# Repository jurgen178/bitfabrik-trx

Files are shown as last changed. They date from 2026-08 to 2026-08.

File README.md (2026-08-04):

# Modular HF SSB Transceiver (Superhet, 9 MHz IF, ESP32 Web Interface)

⚠️ **Work in Progress (WIP) - Active Development**

This repository contains a modular shortwave (HF) amateur radio transceiver currently under development. The project balances a classic, stable analog hardware design with modern network control. 

* **Current State:** Pre-alpha / Experimental. The prototype is initially built for the **40m band**, but engineered from scratch to scale across all HF bands from 160m to 10m.
* **Documentation:** Detailed wiring, schematics, and setup instructions will be published once the hardware architecture and software interfaces stabilize.

---

## 🔍 Key Technical Features (In Progress)

* **Architecture:** Classic Superhet design featuring a 9 MHz Intermediate Frequency (IF) with discrete IF amplification and built-in AGC.
* **Mixing System:** Fully bidirectional passive ADE-1 ring mixer utilized for both Receive (RX) and Transmit (TX) switching via relays.
* **Signal Chain:** 
  * **RX:** SA612 product detector paired with an TDA7052A audio amplifier.
  * **TX:** TL072 microphone preamp, SA612 SSB modulator, and a single-ended RD16HHF1 PA stage aiming for 15W output with custom L-matching.
* **Control & Oscillators:** Dual AD9850 DDS modules (independent LO and BFO generation) orchestrated by an ESP32.
* **Web UI Control:** Integrated standalone Wi-Fi network interface hosted on the ESP32. Enables platform-independent remote tuning, band switching, mode selection (USB/LSB/CW/RTTY), and a built-in Morse/RTTY interface which will be expanded to support common digital transfer modes.

---

## 📁 Repository Structure

* `/src` — Contains the early-stage ESP32 control software, DDS configuration routines, and the wireless web server interface code.
* *(Upcoming)* `/hardware` — Schematics, component lists, and layout guides tailored for the Manhattan-style build approach will be uploaded here later.

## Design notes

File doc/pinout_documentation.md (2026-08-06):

# Anschlussplan (Pinout) - Arduino Nano ESP32

Diese Dokumentation zeigt die exakte physische Verbindung für das **Hosyond 4.0" TN Display** (ST7796S & FT5x06) und alle weiteren Hardware-Komponenten.

## 1. Gemeinsamer I2C-Bus (OLEDs, MCP23017 & Touch)
Alle I2C-Geräte hängen parallel an denselben zwei Leitungen.
- **CTP_SDA** (Touch) geht an **A4**
- **CTP_SCL** (Touch) geht an **A5**

| Signal | GPIO (Code) | Board-Label |
| :--- | :--- | :--- |
| **SDA** | 11 | **A4** |
| **SCL** | 12 | **A5** |

## 2. SPI-Bus (TFT-Display)
| Signal | GPIO (Code) | Board-Label | Display-Pin |
| :--- | :--- | :--- | :--- |
| **SCK** | 48 | **D13** | 7 (SCK) |
| **MOSI** | 38 | **D11** | 6 (SDI) |
| **MISO** | 47 | **D12** | 9 (SDO) |
| **LCD_CS** | 18 | **D9** | 3 (CS) |
| **LCD_RS** | 21 | **D10** | 5 (RS/DC) |
| **TFT_RST** | -1 | **RST** | 4 (LCD_RST) & 11 (CTP_RST) |

## 3. DDS BUS (Shared Architektur)
| Signal | GPIO (Code) | Board-Label | Ziel |
| :--- | :--- | :--- | :--- |
| **DDS_DATA** | 8 | **D5** | DATA (beide Module) |
| **DDS_WCLK** | 9 | **D6** | WCLK (beide Module) |
| **DDS_RESET**| 17 | **D8** | RESET (beide Module) |
| **LO_FQUD**  | 10 | **D7** | FQUD (nur VFO) |
| **BFO_FQUD** | 44 | **D0** | FQUD (nur BFO) |

## 4. Audio & Bedienelemente
| Funktion | GPIO (Code) | Board-Label |
| :--- | :--- | :--- |
| **Audio Volume PWM** | 13 | **A6** |
| **Encoder A** | 5 | **D2** |
| **Encoder B** | 6 | **D3** |
| **Encoder Btn** | 7 | **D4** |
| **PTT Taste** | 4 | **A3** |
| **SWR FWD** | 2 | **A1** |
| **SWR REF** | 3 | **A2** |
| **RSSI / S-Meter**| 1 | **A0** |
| **ZF_AGC_PWM** | 14 | **A7** |
| **Mic Gain CS**| 43 | **D1** |

## 5. MCP23017 Ausgänge (Getrennte RX/TX Filterbänke)
Der Transceiver nutzt zwei unabhängige Gruppen von je 6 Relais für Empfangs- (RX) und Sende-Filter (TX). Ein automatisches Interlock in der Software stellt sicher, dass immer nur die benötigte Gruppe aktiv ist.

| MCP-Pin | Gruppe | Funktion |
| :--- | :--- | :--- |
| **0 - 5** | **RX Filter** | Slots für 10m, 15m, 20m, 40m, 80m, 160m (Empfang) |
| **8 - 13**| **TX Filter** | Slots für 10m, 15m, 20m, 40m, 80m, 160m (Senden) |
| **7** | **TX Control** | **PA_ACTIVE** / Haupt-Antennenrelais |
| **6** | **RESERVE** | Frei |
| **14 - 15**| **RESERVE** | Frei |

## 6. Ressourcen-Check
- **Native GPIOs**: 0 frei (Alle Header-Pins belegt).
- **MCP23017 Pins**: 8 frei.
- **Interne RGB-LED**: Rot (46), Grün (0), Blau (45) - für Statusmeldungen reserviert.

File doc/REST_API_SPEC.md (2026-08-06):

# BITFABRIK Transceiver REST API Specification

This document describes the REST API and communication interfaces for the BITFABRIK Transceiver.

## 1. Web Interfaces

| Method | Path | Description |
| :--- | :--- | :--- |
| `GET` | `/` | Main Control Dashboard (HTML) |
| `GET` | `/bands` | Band Configuration Editor (HTML) |

## 2. Configuration API

| Method | Path | Description |
| :--- | :--- | :--- |
| `GET` | `/bands.json` | Retrieves current band configuration in JSON format. |
| `POST` | `/bands.json` | Saves a new band configuration. Triggers ESP restart. |
| `DELETE` | `/bands.json` | Resets band configuration to defaults. Triggers ESP restart. |

### Band Configuration Schema
Die Datei `/bands.json` steuert die Hardware-Filter und Frequenzbereiche.
**Struktur (Array von Objekten):**
```json
[
  {
    "id": "40m",
    "min": 7000000,
    "max": 7200000,
    "def": 7047000,
    "rx_filter": 3,
    "tx_filter": 3,
    "usb": false,
    "active": true
  }
]
```

### Band Management Examples
**Band-Tabelle hochladen (Überschreiben):**
```bash
curl -X POST -H "Content-Type: application/json" --data-binary @my_bands.json "http://192.168.1.110/bands.json"
```

**Band-Tabelle zurücksetzen (löscht /bands.json auf dem ESP):**
```bash
curl -X DELETE "http://192.168.1.110/bands.json"
```

## 3. Real-Time Status & Control

### Status Update
**`GET /api/v1/status`**
Returns the complete system state as a JSON object.

### Device Control
**`GET/POST /api/v1/control`**
Updates hardware parameters. Multiple parameters can be combined in one request.

**Parameters:**
*   `ui_mode`: `RADIO`, `GEN`, `SETTINGS`, `RIT`
*   `freq`: Frequency in Hz (e.g., `7100000`)
*   `vol`: Audio Volume (0-100)
*   `pwr`: PA Drive Power (0-100)
*   `mic`: Mic Gain (0-100)
*   `band`: Band Index (0-5)
*   `mode`: Digital Mode (0=Morse, 1=RTTY)
*   `vfo_set`: Switch VFO (0=A, 1=B)
*   `vfo_copy`: Trigger A=B sync (any value)
*   `rit_enable`: Enable RIT (0=Off, 1=On)
*   `rit_offset`: RIT Offset in Hz
*   `mem_store`: Store current VFO in Memory Slot (0-9)
*   `mem_recall`: Recall VFO from Memory Slot (0-9)
*   `step`: Tuning Step Index
*   `vox_enable`: Toggle/Set VOX state
*   `vox_thresh`: VOX ADC Threshold (0-4095)
*   `vox_delay`: VOX Release Delay in ms

## 4. Messaging & Transmission

### Digital Transmission
**`GET/POST /api/v1/transmit`**
Queues text for digital transmission.
*   `text`: The string to transmit.

### Radio Email (APRS/JS8 Gateway)
**`GET/POST /api/v1/email`**
Sends an email via radio gateway.
*   `to`: Recipient email address.
*   `msg`: Email body (max 67-100 chars).
*   `gw`: Gateway type (`aprs` or `js8`).

## 5. Streaming & Real-Time Events

### WebSocket
**`WS /ws`**
Primary bi-directional channel for real-time operation.
*   **Downlink:** Sends `JSON_STATUS:{...}` and `RX:<char>`
*   **Uplink:** Accepts `SET:<key>:<value>`, `TX:<text>`, and `MAIL|<to>|<msg>|<gw>`

### Server-Sent Events (SSE)
**`GET /api/v1/rx/stream`**
Event stream for decoded RX characters.
*   Event: `rx_char`

## 6. Usage Examples

Replace `192.168.1.110` with your transceiver's actual IP address.

### Control Examples (curl)
**Set frequency to 7.100 MHz:**
```bash
curl "http://192.168.1.110/api/v1/control?freq=7100000"
```

### PowerShell Example (Windows)
PowerShell ist ideal für kleine Desktop-Scripts.
**Frequenz setzen und Status abrufen:**
```powershell
# Frequenz auf 14.250 MHz setzen
Invoke-RestMethod -Uri "http://192.168.1.110/api/v1/control?freq=14250000"

# Aktuellen Status abholen und Frequenz anzeigen
$status = Invoke-RestMethod -Uri "http://192.168.1.110/api/v1/status"
Write-Host "Aktuelle Frequenz: $($status.freq / 1e6) MHz"
```

### Python Example
Ideal für Automatisierung oder Logging. Benötigt die `requests` Bibliothek.
```python
import requests

# Frequenz setzen
params = {'freq': 7047000, 'vol': 40}
r = requests.get("http://192.168.1.110/api/v1/control", params=params)

# Status auslesen
status = requests.get("http://192.168.1.110/api/v1/status").json()
print(f"SWR: {status['swr']} | Power: {status['power_w']}W")
```

### JavaScript / Node.js (Fetch API)
```javascript
// Frequenz ändern
fetch("http://192.168.1.110/api/v1/control?freq=3600000")
  .then(response => console.log("Status: " + response.status));

// Status periodisch abfragen
async function getStatus() {
  const res = await fetch("http://192.168.1.110/api/v1/status");
  const data = await res.json();
  console.log(`RSSI: ${data.rssi} dBm`);
}
```

### Messaging Examples

**Set Volume to 50% and switch to VFO B:**
```bash
curl "http://192.168.1.110/api/v1/control?vol=50&vfo_set=1"
```

**Toggle VOX System:**
```bash
curl "http://192.168.1.110/api/v1/control?vox_enable=1"
```

### Messaging Examples
**Send "CQ CQ DE BITFABRIK" in current digital mode:**
```bash
curl --data "text=CQ CQ DE BITFABRIK" "http://192.168.1.110/api/v1/transmit"
```

**Send a Radio Email via APRS Gateway:**
```bash
curl "http://192.168.1.110/api/v1/email?to=test@example.com&msg=Hello+from+Radio&gw=aprs"
```

### WebSocket Example (JavaScript)
```javascript
const ws = new WebSocket('ws://192.168.1.110/ws');

ws.onmessage = (event) => {
    if (event.data.startsWith('JSON_STATUS:')) {
        const status = JSON.parse(event.data.substring(12));
        console.log("Current Frequency:", status.freq);
    }
};

// Send command via WebSocket
ws.onopen = () => {
    ws.send("SET:freq:14250000");
};
```

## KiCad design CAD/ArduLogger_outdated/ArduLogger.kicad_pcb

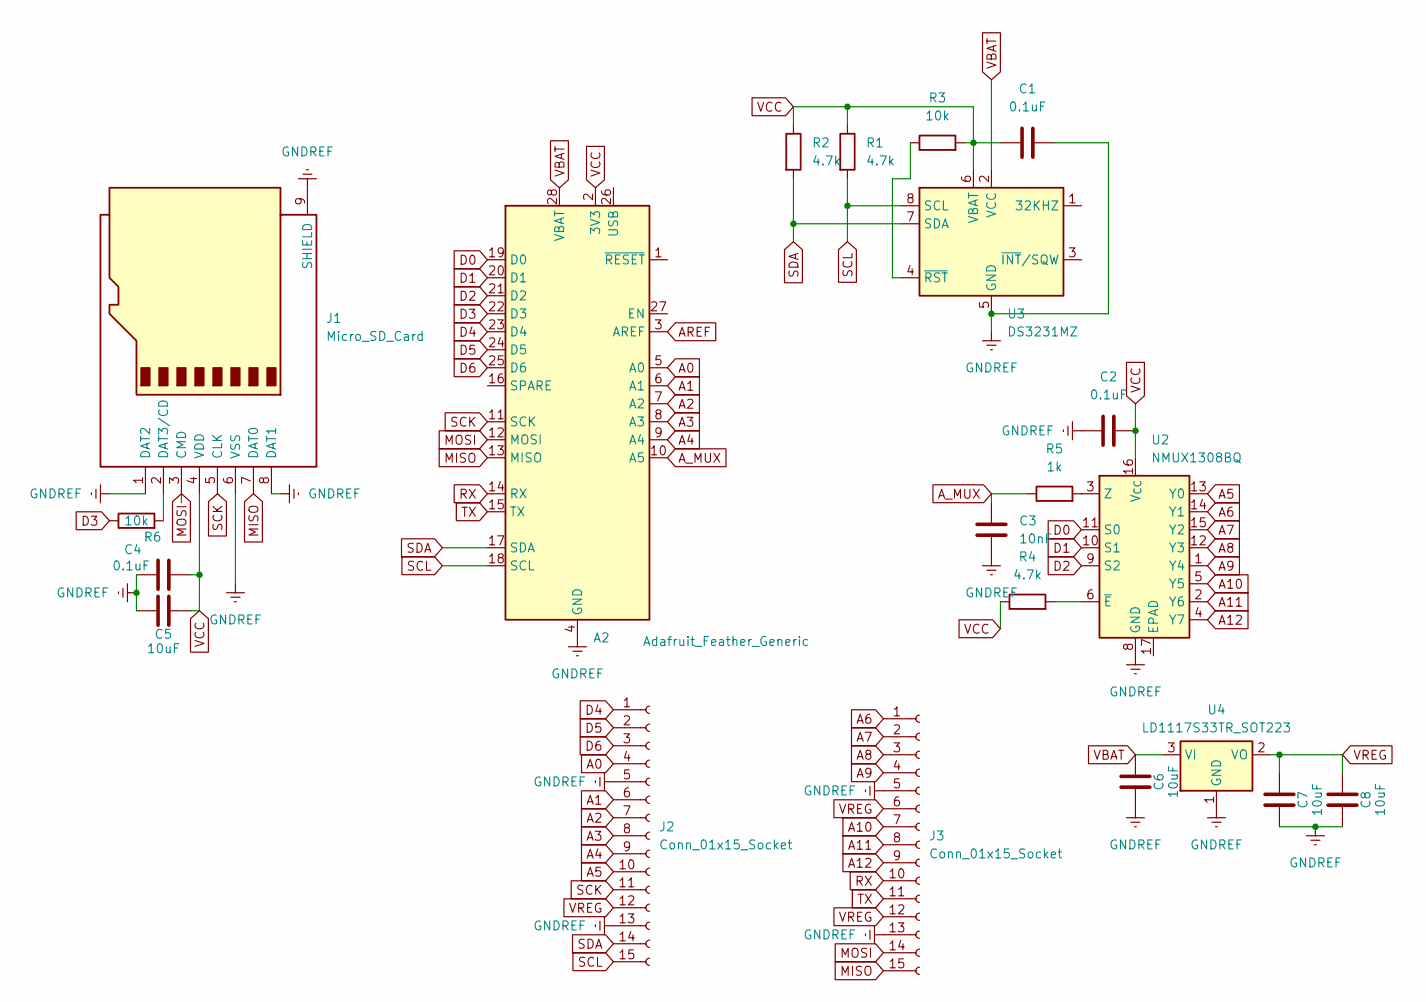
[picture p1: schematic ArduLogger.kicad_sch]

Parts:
A2: Adafruit_Feather_Generic; Adafruit_Feather
C1, C2, C4: 0.1uF; C_0603_1608Metric
C3: 10nF; C_0603_1608Metric
C5, C6, C7, C8: 10uF; C_0603_1608Metric
J1: Micro_SD_Card; microSD_HC_Wuerth_693072010801
J2, J3: Conn_01x15_Socket; PhoenixContact_MSTBVA_2,5_15-G-5,08_1x15_P5.08mm_Vertical
R1, R2, R4: 4.7k; R_0603_1608Metric
R3, R6: 10k; R_0603_1608Metric
R5: 1k; R_0603_1608Metric
U2: NMUX1308BQ; DHVQFN-16-1EP_2.5x3.5mm_P0.5mm_EP1x2mm
U3: DS3231MZ; SOIC-8_3.9x4.9mm_P1.27mm
U4: LD1117S33TR_SOT223; SOT-223-3_TabPin2

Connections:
A0: A2.5 (A0), J2.4
A1: A2.6 (A1), J2.6
A2: A2.7 (A2), J2.7
A3: A2.8 (A3), J2.8
A4: A2.9 (A4), J2.9
A5: J2.10, U2.13 (Y0)
A6: J3.1, U2.14 (Y1)
A7: J3.2, U2.15 (Y2)
A8: J3.3, U2.12 (Y3)
A9: J3.4, U2.1 (Y4)
A10: J3.7, U2.5 (Y5)
A11: J3.8, U2.2 (Y6)
A12: J3.9, U2.4 (Y7)
AREF: A2.3 (AREF)
A_MUX: A2.10 (A5), C3.1, R5.1
D0: A2.19 (D0), U2.11 (S0)
D1: A2.20 (D1), U2.10 (S1)
D2: A2.21 (D2), U2.9 (S2)
D3: A2.22 (D3), R6.1
D4: A2.23 (D4), J2.1
D5: A2.24 (D5), J2.2
D6: A2.25 (D6), J2.3
GNDREF: A2.4 (GND), C1.2, C2.1, C3.2, C4.1, C5.1, C6.1, C7.1, C8.1, J1.1 (DAT2), J1.6 (VSS), J1.8 (DAT1), J1.9 (SHIELD), J2.5, J2.13, J3.5, J3.13, U2.8 (GND), U3.5 (GND), U4.1 (GND)
MISO: A2.13 (MISO), J1.7 (DAT0), J3.15
MOSI: A2.12 (MOSI), J1.3 (CMD), J3.14
unnamed: J1.2 (DAT3/CD), R6.2
unnamed: R5.2, U2.3 (Z)
unnamed: R4.2, U2.6 (~E)
unnamed: R3.1, U3.4 (~RST)
RX: A2.14 (RX), J3.10
SCK: A2.11 (SCK), J1.5 (CLK), J2.11
SCL: A2.18 (SCL), J2.15, R1.2, U3.8 (SCL)
SDA: A2.17 (SDA), J2.14, R2.2, U3.7 (SDA)
TX: A2.15 (TX), J3.11
VBAT: A2.28 (VBAT), C6.2, U3.2 (VCC), U4.3 (VI)
VCC: A2.2 (3V3), C1.1, C2.2, C4.2, C5.2, J1.4 (VDD), R1.1, R2.1, R3.2, R4.1, U2.16 (V_{CC}), U3.6 (VBAT)
VREG: C7.2, C8.2, J2.12, J3.6, J3.12, U4.2 (VO)

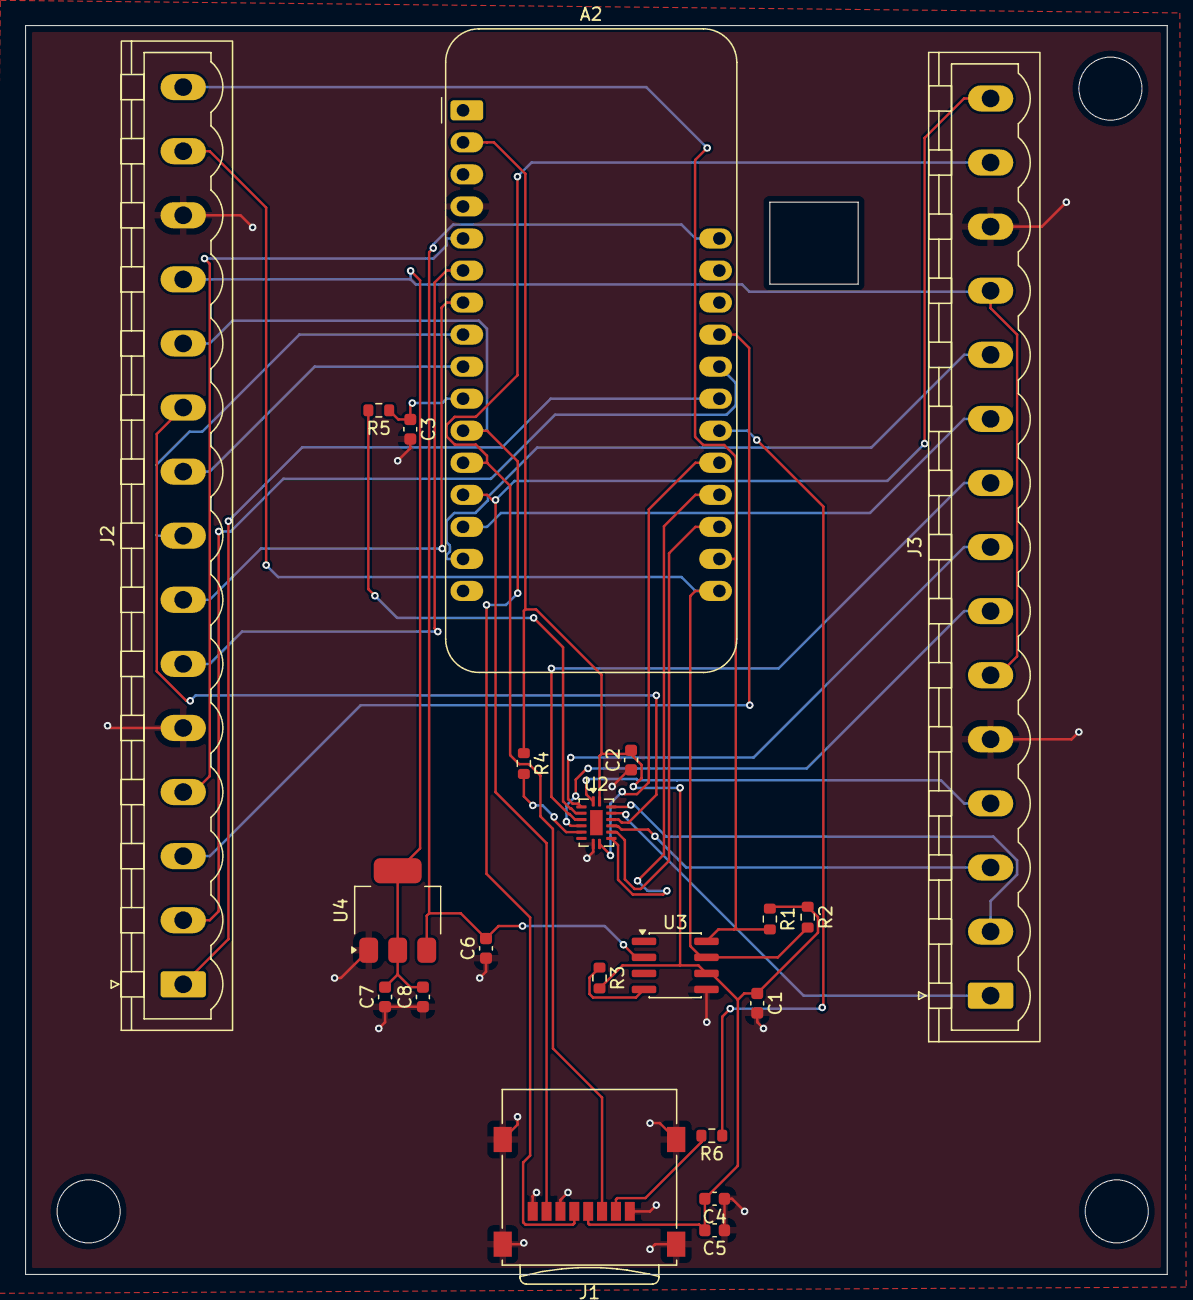
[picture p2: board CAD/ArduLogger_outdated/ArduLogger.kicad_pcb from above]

Board: 2 copper layers, 90.5 x 99.0 mm, 21 parts (0 on the bottom side), 36 nets.

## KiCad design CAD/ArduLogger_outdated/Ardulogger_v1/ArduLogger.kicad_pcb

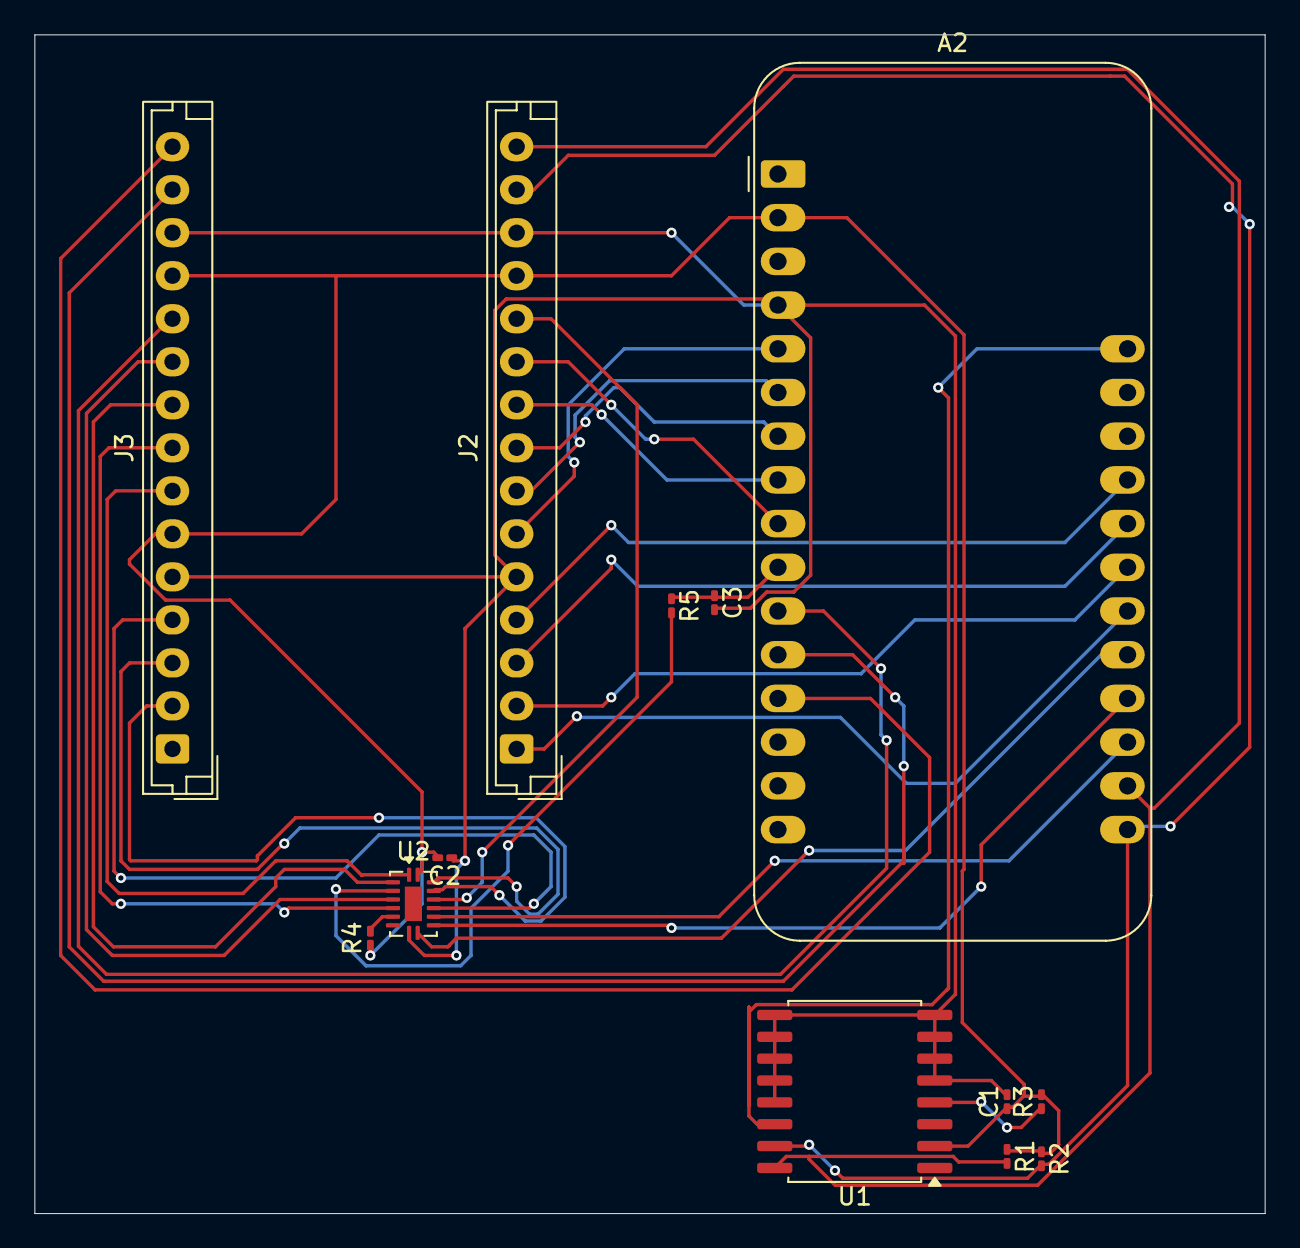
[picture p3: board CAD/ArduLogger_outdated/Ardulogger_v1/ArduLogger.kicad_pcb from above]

Board: 2 copper layers, 71.5 x 68.5 mm, 13 parts (0 on the bottom side), 32 nets.

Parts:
A2: Adafruit_Feather_Generic; Adafruit_Feather
C1, C2: 0.1uF; C_0201_0603Metric_Pad0.64x0.40mm_HandSolder
C3: 10nF; C_0201_0603Metric_Pad0.64x0.40mm_HandSolder
J2, J3: Conn_01x15_Socket; JST_EH_B15B-EH-A_1x15_P2.50mm_Vertical
R1, R2, R4: 4.7k; R_0201_0603Metric_Pad0.64x0.40mm_HandSolder
R3: 10k; R_0201_0603Metric_Pad0.64x0.40mm_HandSolder
R5: 100; R_0201_0603Metric_Pad0.64x0.40mm_HandSolder
U1: DS3231M; SOIC-16W_7.5x10.3mm_P1.27mm
U2: NMUX1308BQ; DHVQFN-16-1EP_2.5x3.5mm_P0.5mm_EP1x2mm

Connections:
A0: A2.5 (A0), J2.6
A1: A2.6 (A1), J2.7
A2: A2.7 (A2), J2.8
A3: A2.8 (A3), J2.9
A4: A2.9 (A4), J2.10
A5: J2.11, U2.13 (Y0)
A6: J3.2, U2.14 (Y1)
A7: J3.3, U2.15 (Y2)
A8: J3.4, U2.12 (Y3)
A9: J3.7, U2.1 (Y4)
A10: J3.8, U2.5 (Y5)
A11: J3.9, U2.2 (Y6)
A12: J3.10, U2.4 (Y7)
A_MUX: A2.10 (A5), C3.1, R5.1
D0: A2.19 (D0), U2.11 (S0)
D1: A2.20 (D1), U2.10 (S1)
D2: A2.21 (D2), U2.9 (S2)
D3: A2.22 (D3), J2.1
D4: A2.23 (D4), J2.2
D5: A2.24 (D5), J2.3
D6: A2.25 (D6), J2.4
GNDREF: A2.4 (GND), C1.2, C2.1, C3.2, J2.5, J2.13, J3.5, J3.13, U1.5 (GND), U1.6 (GND), U1.7 (GND), U1.8 (GND), U1.9 (GND), U1.10 (GND), U1.11 (GND), U1.12 (GND), U1.13 (GND), U2.8 (GND)
MISO: A2.13 (MISO), J3.15
MOSI: A2.12 (MOSI), J3.14
unnamed: A2.28 (VBAT), U1.14 (VBAT)
unnamed: R3.1, U1.4 (~RST)
unnamed: R5.2, U2.3 (Z)
unnamed: R4.2, U2.6 (~E)
SCK: A2.11 (SCK), J3.11
SCL: A2.18 (SCL), J2.15, R1.2, U1.16 (SCL)
SDA: A2.17 (SDA), J2.14, R2.2, U1.15 (SDA)
VCC: A2.2 (3V3), C1.1, C2.2, J2.12, J3.6, J3.12, R1.1, R2.1, R3.2, R4.1, U1.2 (VCC), U2.16 (V_{CC})

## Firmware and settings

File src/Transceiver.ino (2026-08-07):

/**
 * ── BITFABRIK Transceiver v1.0 ──────────────────────────────────────────
 */

#include <FFat.h>
#include "Constants.h"
#include "Globals.h"
#include "Hardware.h"
#include "Display.h"
#include "DigitalEngine.h"
#include "Network.h"
#include "EncoderActions.h"
#include "RadioEngine.h"
#include "AudioManager.h"
#include "SettingsManager.h"
#include "LogManager.h"

// ── GLOBAL STATE ALLOCATION ───────────────────────────────────────────────

std::atomic<bool> g_tx(false);
std::atomic<bool> g_mcpOk(false);
std::atomic<unsigned long> g_lastActivityTime(0);
SyncState g_sync;

// UI Synchronization
std::atomic<bool> g_guiNeedsUpdate(true);
TaskHandle_t  g_networkTaskHandle = NULL;

// System Health
volatile int g_cpuLoad0 = 0;
volatile int g_cpuLoad1 = 0;
volatile int g_wifiRssi = -100;
volatile int g_webClients = 0;
volatile int g_netActivity = 0;

// Encoder State Machine
volatile int  g_encPos      = 0;
volatile unsigned long g_lastEncMove = 0;
volatile unsigned long g_encInterval = 999;
volatile uint8_t g_oldEncState = 0;
volatile int8_t  s_encAccum  = 0;
const int8_t ENC_STATES[] = { 0, -1, 1, 0, 1, 0, 0, -1, -1, 0, 0, 1, 0, 1, -1, 0 };

// ── HARDWARE SINGLETONS ───────────────────────────────────────────────────

LGFX_TRX tft;
Adafruit_SSD1306 display1(SCREEN_WIDTH, SCREEN_HEIGHT, &Wire, OLED_RESET);
Adafruit_SSD1306 display2(SCREEN_WIDTH, SCREEN_HEIGHT, &Wire, OLED_RESET);
Adafruit_MCP23X17 mcp;
Preferences preferences;
EncoderManager encManager;

SemaphoreHandle_t g_mutex;
SemaphoreHandle_t g_hwMutex;

// ── CONSTANT DATA (defined in Constants.cpp) ─────────────────────────────
// extern declarations are in Globals.h

// ── SYSTEM BOOT ───────────────────────────────────────────────────────────

void setup()
{
  Serial.begin(115200);
  delay(2000); // Give user time to open monitor
  Serial.println("\n\n--- BITFABRIK Transceiver Start ---");

  // Init concurrency locks
  g_mutex = xSemaphoreCreateMutex();
  g_hwMutex = xSemaphoreCreateRecursiveMutex();

  // Basic I/O
  pinMode(LED_RED, OUTPUT);
  digitalWrite(LED_RED, HIGH);

  // FFat Filesystem
  Serial.println("FS: Initializing FFat...");
  if (!FFat.begin(false)) {
      Serial.println("FS: FFat mount failed. Formatting...");
      FFat.begin(true);
  }
  Serial.println("FS: OK");

  Serial.println("I2C: Initializing...");
  Wire.begin();
  Wire.setClock(200000); // Stable 200kHz for multiple devices
  Wire.setTimeOut(100); // Prevent hang if device missing
  Serial.println("I2C: Scan start...");
  for (uint8_t address = 1; address < 127; address++)
  {
    Wire.beginTransmission(address);
    if (Wire.endTransmission() == 0)
    {
      Serial.printf("I2C: Found device at 0x%02X\n", address);
    }
  }

  // MCP23017 Expander Init
  Serial.println("MCP: Initializing...");
  if (!mcp.begin_I2C(0x27))
  {
      Serial.println("MCP: ERR - Not found at 0x27");
      g_mcpOk = false;
  }
  else
  {
      Serial.println("MCP: OK");
      g_mcpOk = true;
      // Initialize all 16 pins to a safe state
      for (int i = 0; i < 16; i++)
      {
          if (i == MCP_PIN_PTT)
          {
              mcp.pinMode(i, INPUT_PULLUP);
          }
          else
          {
              mcp.pinMode(i, OUTPUT);
              mcp.digitalWrite(i, LOW); // Ensure all relays/PA_ACTIVE are OFF
          }
      }
  }

  // Hardware Pin Config
  Serial.println("HW: Configuring pins...");
  const int busPins[] = { DDS_DATA, DDS_WCLK, DDS_RESET, LO_FQUD, BFO_FQUD };
  for (int p : busPins)
  {
      pinMode(p, OUTPUT);
  }
  pinMode(AUDIO_VOLUME_PWM, OUTPUT);
  pinMode(ZF_AGC_PWM, OUTPUT);
  pinMode(MIC_CS, OUTPUT);
  digitalWrite(MIC_CS, HIGH);
  pinMode(ENC_A, INPUT);
  pinMode(ENC_B, INPUT);
  pinMode(ENC_BTN, INPUT_PULLUP);

  // Encoder ISR Setup
  g_oldEncState = (digitalRead(ENC_A) << 1) | digitalRead(ENC_B);
  if (ENC_TYPE == 1)
  {
    attachInterrupt(digitalPinToInterrupt(ENC_A), encISR_Optical, CHANGE);
    attachInterrupt(digitalPinToInterrupt(ENC_B), encISR_Optical, CHANGE);
  }
  else
  {
    attachInterrupt(digitalPinToInterrupt(ENC_A), encISR, CHANGE);
    attachInterrupt(digitalPinToInterrupt(ENC_B), encISR, CHANGE);
  }

  // Visuals & Touch
  Serial.println("TFT: Initializing (ST7796S)...");
  tft.init();
  tft.setRotation(1);
  tft.fillScreen(TFT_BLACK);
  Serial.println("TFT: OK");

  Serial.println("OLED: Initializing Display 1 (0x3C)...");
  if(!display1.begin(SSD1306_SWITCHCAPVCC, OLED_ADRESSE_A))
  {
    Serial.println("OLED 1: ERR");
  }
  else
  {
    display1.clearDisplay();
    display1.display(); // Force clear to avoid "snow" at start
    Serial.println("OLED 1: OK");
  }

  Serial.println("OLED: Initializing Display 2 (0x3D)...");
  if(!display2.begin(SSD1306_SWITCHCAPVCC, OLED_ADRESSE_B))
  {
    Serial.println("OLED 2: ERR");
  }
  else
  {
    display2.clearDisplay();
    display2.display();
    Serial.println("OLED 2: OK");
  }

  Serial.println("DDS: Syncing bus...");
  dds_reset(); // Bus synchronization

  Serial.println("Settings: Loading...");
  settings.begin();
  logger.begin();

  Serial.println("Audio: Starting PWM...");
  audio.begin();

  Serial.println("Radio: Loading dynamic configuration...");
  radio.loadBandsFromJson();

  Serial.println("Radio: Setting default band...");
  ui.begin();
  radio.selectBand(radio.getBand());
  ui.drawFullUI();

  encManager.begin();

  // Multi-Core Task Scheduling - START LAST
  Serial.println("OS: Starting Background Services...");
  xTaskCreatePinnedToCore(TaskNetwork, "Network", 8192, NULL, 1, NULL, 0); // Core 0: Comm Background
  xTaskCreatePinnedToCore(TaskDigital, "Digital", 4096, NULL, 2, NULL, 0); // Core 0: FSK Timing

  Serial.println("OS: Starting Radio...");
  xTaskCreatePinnedToCore(TaskRadio,   "Radio",   8192, NULL, 3, NULL, 1); // Core 1: Hardware High Priority

  Serial.println("BOOT COMPLETE.");
}

void loop()
{
  // Tasks are managed by FreeRTOS. loop() just yields.
  vTaskDelay(pdMS_TO_TICKS(1000));
}

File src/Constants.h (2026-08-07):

#ifndef CONSTANTS_H
#define CONSTANTS_H

#include <Arduino.h>

/**
 * ── BITFABRIK Transceiver v3.0 ──────────────────────────────────────────
 * Central Hardware Configuration (Pins, Constants, and i18n).
 *
 * Target Board: Arduino Nano ESP32 (ESP32-S3)
 * NOTE: Ensure "By GPIO number (standard)" is selected in Tools -> Pin Numbering.
 * ──────────────────────────────────────────────────────────────────────────
 */

// ── Build Flags ───────────────────────────────────────────────────────────
#define DEBUG_SIM // Enable simulated RSSI/SWR and dummy RX decode (no hardware needed)

// ── Internationalization (i18n) ──────────────────────────────────────────
#define LANG_DE // Standard auf Deutsch für Tests

#if defined(LANG_DE)
  #define L_I2C_OK        "I2C initialisiert (400kHz)"
  #define L_MCP_ERR       "MCP23017 Fehler!"
  #define L_MCP_OK        "MCP23017 initialisiert"
  #define L_ENC_OPTICAL   "Encoder: Optisch (EM14)"
  #define L_ENC_MECHANIC  "Encoder: Mechanisch (KY-040)"
  #define L_TFT_TOUCH_OK  "ILI9488 & Touch bereit"
  #define L_DISP1_ERR     "Display 1 (0x3C) Fehler!"
  #define L_DISP2_ERR     "Display 2 (0x3D) Fehler!"
  #define L_PREFS_SAVED   "Einstellungen gespeichert."
  #define L_SYS_STARTED   "System gestartet."
  #define L_WIFI_CONN     "Verbinde mit Heimnetzwerk..."
  #define L_WIFI_FAIL     "Statische IP Konfiguration fehlgeschlagen!"
  #define L_AP_START      "\n=== Access Point gestartet ==="
  #define L_WIFI_OK       "\n=== WiFi Station verbunden ==="
  #define L_WIFI_ERR      "\n=== Heimnetzwerk nicht erreichbar ==="
  #define L_AP_MSG        "Bitte mit 'TRX-1-Hotspot' verbinden"
  #define L_TX_ON         "Radio Task: TX -> AN"
  #define L_TX_OFF        "Radio Task: TX -> AUS"
  #define L_SWR_ALARM     "!!! SWR ALARM: %.1f !!!"
  #define L_SSE_CONN      "SSE: Client verbunden."
  #define L_API_TX        "API v1: Sende-Anfrage: "
  #define L_SWR_ALARM_AUX "AUX: SWR ALARM!"
  #define L_BAND          "Band"
  #define L_MODE          "Modus"
  #define L_SEQ_RX_TX     "Sequenzer: RX -> TX bereit"
  #define L_SEQ_TX_RX     "Sequenzer: TX -> RX bereit"
  #define L_MEM_CHANNELS  "MEM:"
  #define L_STEP          "Schritt"
  #define L_CALIBRATION   "KALIBRIERUNG"
  #define L_TX_ACTIVE     "TX: AKTIV"
  #define L_RX            "RX"
  #define L_DIGITAL_MODE  "Digital:"
  #define L_TIME_UTC      "Zeit UTC:"
  #define L_TIME          "Zeit:"
  #define L_UPTIME        "Uptime"
  #define L_FREE          "Frei"
  #define L_WAIT_SIGNAL   "Warte auf Signal..."
  #define H_LIVE_MONITOR  "Live Station"
  #define H_SIGNAL_HEALTH "Signal & Status"
  #define H_TUNING_CONTROLS "Abstimmung"
  #define H_DIGI_MSG      "Digitaler Funk"
  #define H_MAIL_GW       "Radio Email Gateway"
  #define H_DECODED       "Decoder Stream"
  #define H_TUNING_KNOB   "Abstimmung"
  #define H_DIGI_MODE     "Digitaler Modus"
  #define H_TRANSMIT      "Senden"
  #define H_CARRIER       "Träger"
  #define H_IDLE          "BEREIT"
  #define H_SENDING       "SENDET"
  #define H_MSG_PLACEHOLDER "Nachricht eingeben..."
  #define H_SEND_BTN      "Senden"
  #define H_DECODED_STREAM "Decodierter Stream"
  #define H_CLEAR_BTN     "Löschen"
  #define H_MEM_CHANNELS  "Speicherkanäle"
  #define H_SAVE_TO       "Speichern in:"
  #define H_STORE_BTN     "Sichern"
  #define H_BAND_MODE     "Band & Modus"
  #define L_MIC_GAIN      "Mic Gain"
  #define L_WAITING       "Warten..."
  #define L_SEND          "Senden"
  #define L_RIT_ON        "RIT AN"
  #define L_RIT_OFF       "RIT AUS"
  #define L_IDLE          "IDLE"
  #define L_SENDING       "SENDET"
  #define L_VOL           "Lautstärke"
  #define TX_PWR_CTRL     "Sendeleistung"
  #define L_MORSE_MODE    "Morse Modus"
  #define L_RTTY_MODE     "RTTY Modus"
  #define L_TX_STATUS     "Sende-Status"
  #define L_MAIL_RECIPIENT "Empfänger"
  #define L_MAIL_BODY     "Inhalt..."
  #define L_SAVE_TO       "SICHERN IN"
  #define L_SICHERN       "Sichern"
  #define L_SIGNAL_GEN    "SIGNALGENERATOR"
  #define L_BACK          "ZURUECK"
  #define L_PA_DISABLED   "Endstufe inaktiv"
  #define L_TAB_VOX       "VOX"
  #define L_TAB_TIME      "ZEIT"
  #define L_VOX_ACTIVE    "VOX Aktiv"
  #define L_VOX_THRESH    "VOX Pegel"
  #define L_VOX_DELAY     "VOX Haltezeit"
  #define L_UTC_OFFSET    "UTC Versatz"
  #define L_DST           "Sommerzeit"
#elif defined(LANG_EN)
  #define L_I2C_OK        "I2C initialized at 400kHz"
  #define L_MCP_ERR       "MCP23017 Error!"
  #define L_MCP_OK        "MCP23017 initialized"
  #define L_ENC_OPTICAL   "Encoder: Optical Mode (EM14)"
  #define L_ENC_MECHANIC  "Encoder: Mechanical Mode (KY-040)"
  #define L_TFT_TOUCH_OK  "ILI9488 & Touch initialized"
  #define L_DISP1_ERR     "Display 1 (0x3C) failed!"
  #define L_DISP2_ERR     "Display 2 (0x3D) failed!"
  #define L_PREFS_SAVED   "Settings saved."
  #define L_SYS_STARTED   "System started."
  #define L_WIFI_CONN     "Connecting to home network"
  #define L_WIFI_FAIL     "Static IP configuration failed!"
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

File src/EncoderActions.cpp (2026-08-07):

#include "EncoderActions.h"
#include "Hardware.h"
#include "RadioEngine.h"
#include "AudioManager.h"
#include "SettingsManager.h"
#include "Display.h"

/**
 * ── TUNE HANDLER ──────────────────────────────────────────────────────────
 * Standard frequency control mode with speed-sensitive acceleration.
 * ──────────────────────────────────────────────────────────────────────────
 */
void TuneHandler::onRotate(int delta)
{
    if (g_tx)
    {
        return; // Prevent frequency change during transmission
    }
    long mult = 1;
    unsigned long dT = g_encInterval; // Use the true physical interval measured in ISR

    // Dynamic acceleration logic - Separated by hardware type
#if ENC_TYPE == 1
    // Optical Encoder (High pulse rate)
    if (dT < 6)
    {
        mult = 20; // Turbo
    }
    else if (dT < 12)
    {
        mult = 10; // Fast
    }
    else if (dT < 25)
    {
        mult = 4; // Medium
    }
    // > 25ms is 1:1 precision
#else
    // Mechanical Encoder (Low pulse rate)
    if (dT < 30)
    {
        mult = 20;
    }
    else if (dT < 60)
    {
        mult = 10;
    }
    else if (dT < 100)
    {
        mult = 4;
    }
#endif

    radio.setFrequency(radio.getFrequency() + delta * STEPS[radio.getStepIdx()] * mult);
}

/**
 * Generates the professional status line for OLED (e.g., "40m - LSB S:1k").
 */
String TuneHandler::getDisplayLabel()
{
    char stepBuf[16];
    long st = STEPS[radio.getStepIdx()];
    if (st >= 1000)
    {
        snprintf(stepBuf, sizeof(stepBuf), "%ldk", st/1000);
    }
    else
    {
        snprintf(stepBuf, sizeof(stepBuf), "%ld", st);
    }

    char buf[48];
    snprintf(buf, sizeof(buf), "%s - %s S:%s", BANDS[radio.getBand()].name, radio.isUsb() ? "USB" : "LSB", stepBuf);
    return String(buf);
}

void TuneHandler::renderFocused(Adafruit_SSD1306 &display)
{
    display.setTextSize(2);
    display.setCursor(0, 18);
    display.printf("%ld.%03ld", radio.getFrequency() / 1000000, (radio.getFrequency() % 1000000) / 1000);
    display.setTextSize(1);
    display.printf(".%03ld", radio.getFrequency() % 1000);
}

/**
 * ── VOLUME HANDLER ────────────────────────────────────────────────────────
 */
void VolumeHandler::onRotate(int delta)
{
    audio.setVolume(audio.getVolume() + delta);
}

String VolumeHandler::getDisplayLabel()
{
    return "VOLUME CONTROL";
}

void VolumeHandler::renderFocused(Adafruit_SSD1306 &display)
{
    display.setTextSize(2);
    display.setCursor(0, 18);
    display.printf("VOL: %d%%", audio.getVolume());
}

/**
 * ── POWER HANDLER ─────────────────────────────────────────────────────────
 */
void PowerHandler::onRotate(int delta)
{
    audio.setPaPower(audio.getPaPower() + delta);
}

String PowerHandler::getDisplayLabel()
{
    return "PA POWER LEVEL";
}

void PowerHandler::renderFocused(Adafruit_SSD1306 &display)
{
    display.setTextSize(2);
    display.setCursor(0, 18);
    display.printf("PWR: %d%%", audio.getPaPower());
}

/**
 * ── MIC GAIN HANDLER ──────────────────────────────────────────────────────
 */
void MicGainHandler::onRotate(int delta)
{
    audio.setMicGain(audio.getMicGain() + delta);
}

String MicGainHandler::getDisplayLabel()
{
    return "MIC GAIN CONTROL";
}

void MicGainHandler::renderFocused(Adafruit_SSD1306 &display)
{
    display.setTextSize(2);
    display.setCursor(0, 18);
    display.printf("MIC: %d%%", audio.getMicGain());
}

/**
 * ── CALIBRATE HANDLER ─────────────────────────────────────────────────────
 */
void CalibrateHandler::onRotate(int delta)
{
    if (radio.isUsb())
    {
        radio.setBfoUsb(radio.getBfoUsb() + delta * 50.0);
    }
    else
    {
        radio.setBfoLsb(radio.getBfoLsb() + delta * 50.0);
    }
    g_guiNeedsUpdate = true;
}

String CalibrateHandler::getDisplayLabel()
{
    return "BFO CALIBRATION";
}

void CalibrateHandler::renderFocused(Adafruit_SSD1306 &display)
{
    display.setTextSize(2);
    display.setCursor(0, 18);
    display.printf("%.1f Hz", radio.isUsb() ? radio.getBfoUsb() : radio.getBfoLsb());
}

/**
 * ── RIT HANDLER ───────────────────────────────────────────────────────────
 */
void RitHandler::onRotate(int delta)
{
    radio.setRitOffset(radio.getRitOffset() + delta * 10); // 10Hz steps
}

String RitHandler::getDisplayLabel()
{
    return "RIT OFFSET";
}

void RitHandler::renderFocused(Adafruit_SSD1306 &display)
{
    display.setTextSize(2);
    display.setCursor(0, 18);
    display.printf("%+ld Hz", radio.getRitOffset());
}

/**
 * ── ENCODER MANAGER ────────────────────────────────────────────────────────
 */
EncoderManager::EncoderManager()
{
}

void EncoderManager::begin()
{
    setMode(EncoderMode::Tune);
}

void EncoderManager::setMode(EncoderMode newMode)
{
    if (newMode == mode && currentHandler) return;

    if (currentHandler)
    {
        currentHandler->onLeave();
    }

    mode = newMode;
    switch(newMode)
    {
        case EncoderMode::Volume:
            currentHandler = &vol;
            ui.setMode(DisplayMode::Volume);
            break;
        case EncoderMode::Power:
            currentHandler = &power;
            ui.setMode(DisplayMode::Power);
            break;
        case EncoderMode::Mic:
            currentHandler = &mic;
            ui.setMode(DisplayMode::Mic);
            break;
        case EncoderMode::Calibrate:
            currentHandler = &cal;
            break;
        case EncoderMode::Rit:
            currentHandler = &rit;
            ui.setMode(DisplayMode::Rit);
            break;
        default:
            currentHandler = &tune;
            ui.setMode(DisplayMode::Radio);
            break;
    }

    currentHandler->onEnter();
    lastActivity = millis();
    g_guiNeedsUpdate = true;
}

void EncoderManager::cycleMode()
{
    if (mode == EncoderMode::Tune)
    {
        setMode(EncoderMode::Volume);
    }
    else if (mode == EncoderMode::Volume)
    {
        setMode(EncoderMode::Power);
    }
    else if (mode == EncoderMode::Rit)
    {
        setMode(EncoderMode::Tune);
    }
    else
    {
        setMode(EncoderMode::Tune);
    }
}

void EncoderManager::handleRotation(int delta)
{
    if (!currentHandler)
    {
        setMode(EncoderMode::Tune);
    }
    currentHandler->onRotate(delta);
    lastActivity = millis();
}

void EncoderManager::checkTimeout()
{
    if (mode != EncoderMode::Tune && mode != EncoderMode::Calibrate)
    {
        if (millis() - lastActivity > 5000)
        {
            setMode(EncoderMode::Tune);
        }
    }
}

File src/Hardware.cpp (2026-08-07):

#include "Hardware.h"
#include "Display.h"
#include "EncoderActions.h"
#include "RadioEngine.h"
#include "AudioManager.h"
#include "SettingsManager.h"
#include "NetworkManager.h"
#include "DigitalEngine.h"
#include "LogManager.h"
#include <SPI.h>

/**
 * ── DDS BUS DRIVER ────────────────────────────────────────────────────────
 * Implements a shared bus for multiple AD9850 modules.
 * Standard wiring:
 * - DATA/WCLK/RESET: Parallel to all modules.
 * - FQUD: Dedicated signal per module (serves as Chip Select).
 * ──────────────────────────────────────────────────────────────────────────
 */

void dds_pulse(int pin)
{
  digitalWrite(pin, HIGH);
  delayMicroseconds(1);
  digitalWrite(pin, LOW);
}

/**
 * Transmits a 40-bit Frequency Tuning Word (FTW) to the selected module.
 */
void dds_setFreq(double freq, int fqud)
{
  if (xSemaphoreTakeRecursive(g_hwMutex, portMAX_DELAY))
  {
    // Formula: FTW = (Freq * 2^32) / Reference_Clock
    uint32_t tw = (uint32_t)((freq / REF_FREQ) * 4294967296.0);

    // Serial transfer (LSB first)
    for (int i = 0; i < 32; i++)
    {
      digitalWrite(DDS_DATA, (tw >> i) & 1);
      dds_pulse(DDS_WCLK);
    }
    // Phase and Control bits (trailing 8 bits, all 0)
    for (int i = 0; i < 8; i++)
    {
      digitalWrite(DDS_DATA, LOW);
      dds_pulse(DDS_WCLK);
    }
    // Frequency Update Pulse (Latch data to DAC)
    dds_pulse(fqud);
    xSemaphoreGiveRecursive(g_hwMutex);
  }
}

/**
 * Hardware Reset for the serial bus interfaces.
 */
void dds_reset()
{
  if (xSemaphoreTakeRecursive(g_hwMutex, portMAX_DELAY))
  {
    digitalWrite(DDS_RESET, HIGH);
    delayMicroseconds(5);
    digitalWrite(DDS_RESET, LOW);
    delayMicroseconds(5);
    dds_pulse(DDS_WCLK); // Sync serial interface
    // Latch both modules to clean state
    dds_pulse(LO_FQUD);
    dds_pulse(BFO_FQUD);
    xSemaphoreGiveRecursive(g_hwMutex);
  }
}

/**
 * ── RF SEQUENCER ──────────────────────────────────────────────────────────
 * Manages the transition between Receive and Transmit modes.
 * Ensures antenna relays and PA bias are switched with safe timing.
 * ──────────────────────────────────────────────────────────────────────────
 */

/**
 * Physical TX/RX switching logic.
 * NOTE: Band filters are now handled only on band selection for stability.
 */
void setTxRx(bool tx)
{
  g_tx = tx;
  logger.notifyTxState(tx);

  if (xSemaphoreTakeRecursive(g_hwMutex, portMAX_DELAY))
  {
    if (g_mcpOk)
    {
      // PA is only active if TX is requested AND we are NOT in Generator Mode (unlocked)
      bool paState = tx && !radio.isUnlocked();
      mcp.digitalWrite(MCP_TX_PA_ACTIVE, paState ? HIGH : LOW);
    }

    // Re-latch band filter relays inside the same mutex block for stability
    radio.refreshRelays();

    xSemaphoreGiveRecursive(g_hwMutex);
  }

  notifyWebUpdate();
}

// ── VFO & STORAGE ─────────────────────────────────────────────────────────

// ── ANALOG/PWM CONTROL ────────────────────────────────────────────────────

/**
 * ── METERING ENGINE ───────────────────────────────────────────────────────
 * Samples Stockton bridge voltages and applies diode knee compensation.
 * ──────────────────────────────────────────────────────────────────────────
 */

static float compensateDiode(float v)
{
  if (v <= 0.001f)
  {
      return 0.0f;
  }
  // Non-linear correction for BAT85 Schottky diode drop
  if (v < SWR_DIODE_VF)
  {
      return sqrtf(v * SWR_DIODE_VF);
  }
  return v + SWR_DIODE_VF;
}
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
